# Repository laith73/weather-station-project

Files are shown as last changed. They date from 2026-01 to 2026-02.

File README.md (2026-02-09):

# Project Description

This is a design for a weather station device that provides multiple essential metrics for real-world weather scenarios. This device can be used in various settings, including homes, farms, and offices, allowing users to gain insight into the weather without leaving the comfort of their own place. Additionally, the device provides a simple web dashboard accessible locally to display the sensors' readings on the user's computer or phone, as well as a small OLED display on the device for easy local monitoring.

This repo contains all of the KiCad project files, reports, and datasheets for the parts used.

# Contributors

- Laith Al Sairafi, laith73@iastate.edu
- Luke Post, lpost@iastate.edu

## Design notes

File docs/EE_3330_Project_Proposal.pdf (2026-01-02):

# EE 3330 Project Proposal - Weather Station

### Laith Al Sairafi and Luke Post

### September 10th 2025

## Project Description and Details

For our project, we plan to design a weather station device that provides multiple essential metrics used in real-world weather scenarios. This device could be used in homes, allowing users to gain insight into the weather without leaving the comfort of their own homes. Additionally, we plan to create a simple web dashboard that can be accessed locally to display the sensors’ readings on the user’s computer or phone. Since the ESP32 microcontroller features a built-in WiFi module, as well as a small display, it will facilitate easy local monitoring.

The sensors we are planning to use for this project are the following:

- Temperature
- Humidity
- Barometric pressure
- UV
- GPS

However, depending on the project’s progress throughout the semester, more sensors could be added later.

## Team Members

- Laith Al Sairafi, email: laith73@iastate.edu
- Luke Post, email: lpost@iastate.edu

1

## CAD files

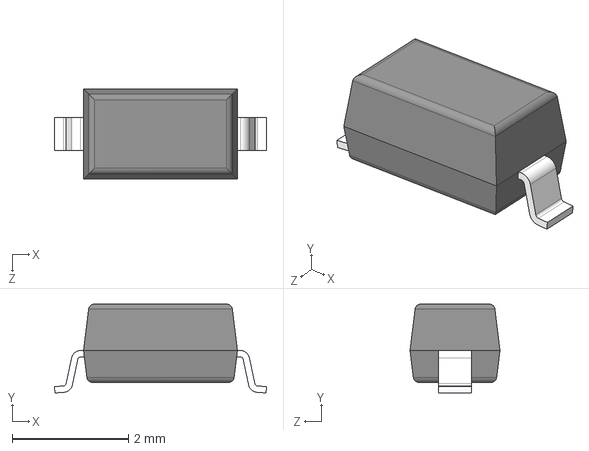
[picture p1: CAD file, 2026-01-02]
kicad files/Models/1N5819HW_7_F/1N5819HW-7-F.step
3.65 x 1.53 x 1.55 mm

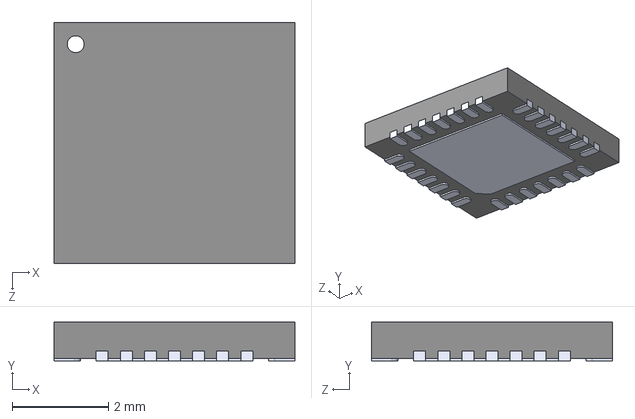
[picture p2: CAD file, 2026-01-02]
kicad files/Models/CP2102N_A02_GQFN28/CP2102N-A02-GQFN28.step
5.00 x 0.8 x 5.00 mm

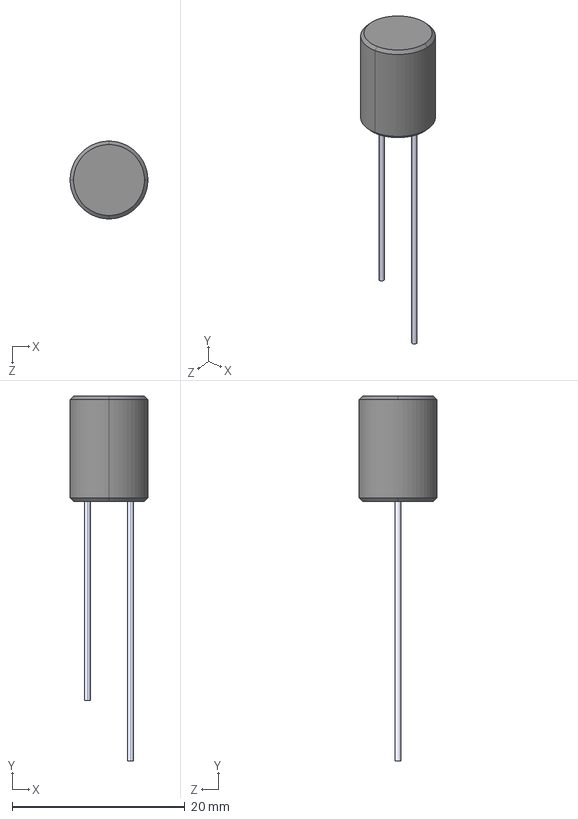
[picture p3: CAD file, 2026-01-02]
kicad files/Models/RLB9012_221KL/RLB9012-221KL.step
9.00 x 42.2 x 9.00 mm

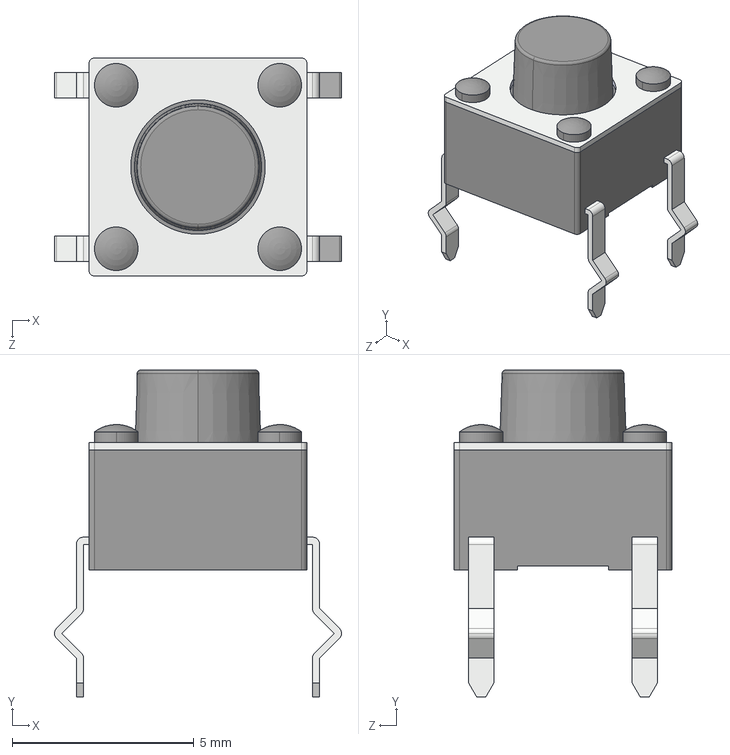
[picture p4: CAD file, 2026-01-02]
kicad files/Models/TS02_66_55_BK_100_LCR_D/TS02-66-55-BK-100-LCR-D.step
7.90 x 9.00 x 6.00 mm

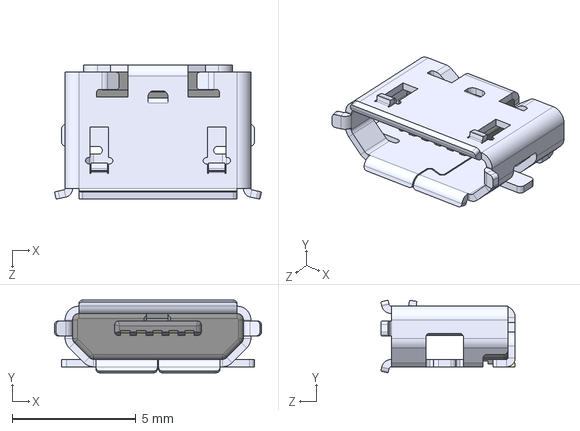
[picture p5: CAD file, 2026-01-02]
kicad files/Models/473460001/47346-0001.step
8.36 x 2.94 x 5.43 mm

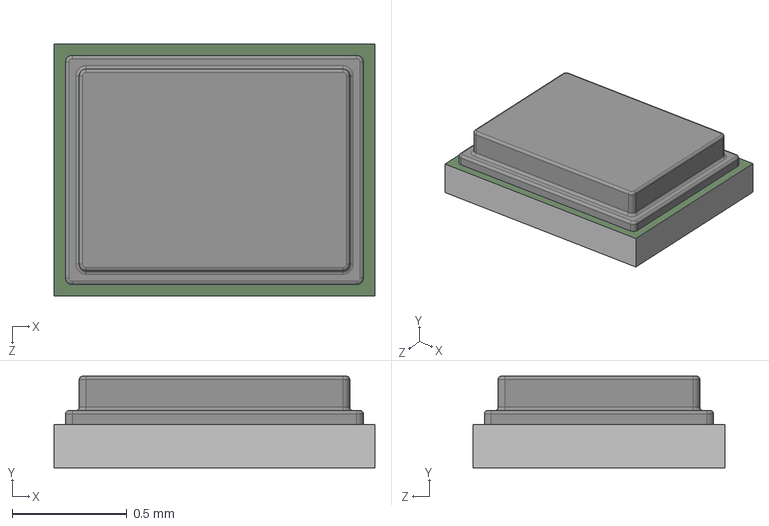
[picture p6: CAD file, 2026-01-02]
kicad files/Models/B4327/B39162B4327P810.step
1.40 x 0.4 x 1.10 mm

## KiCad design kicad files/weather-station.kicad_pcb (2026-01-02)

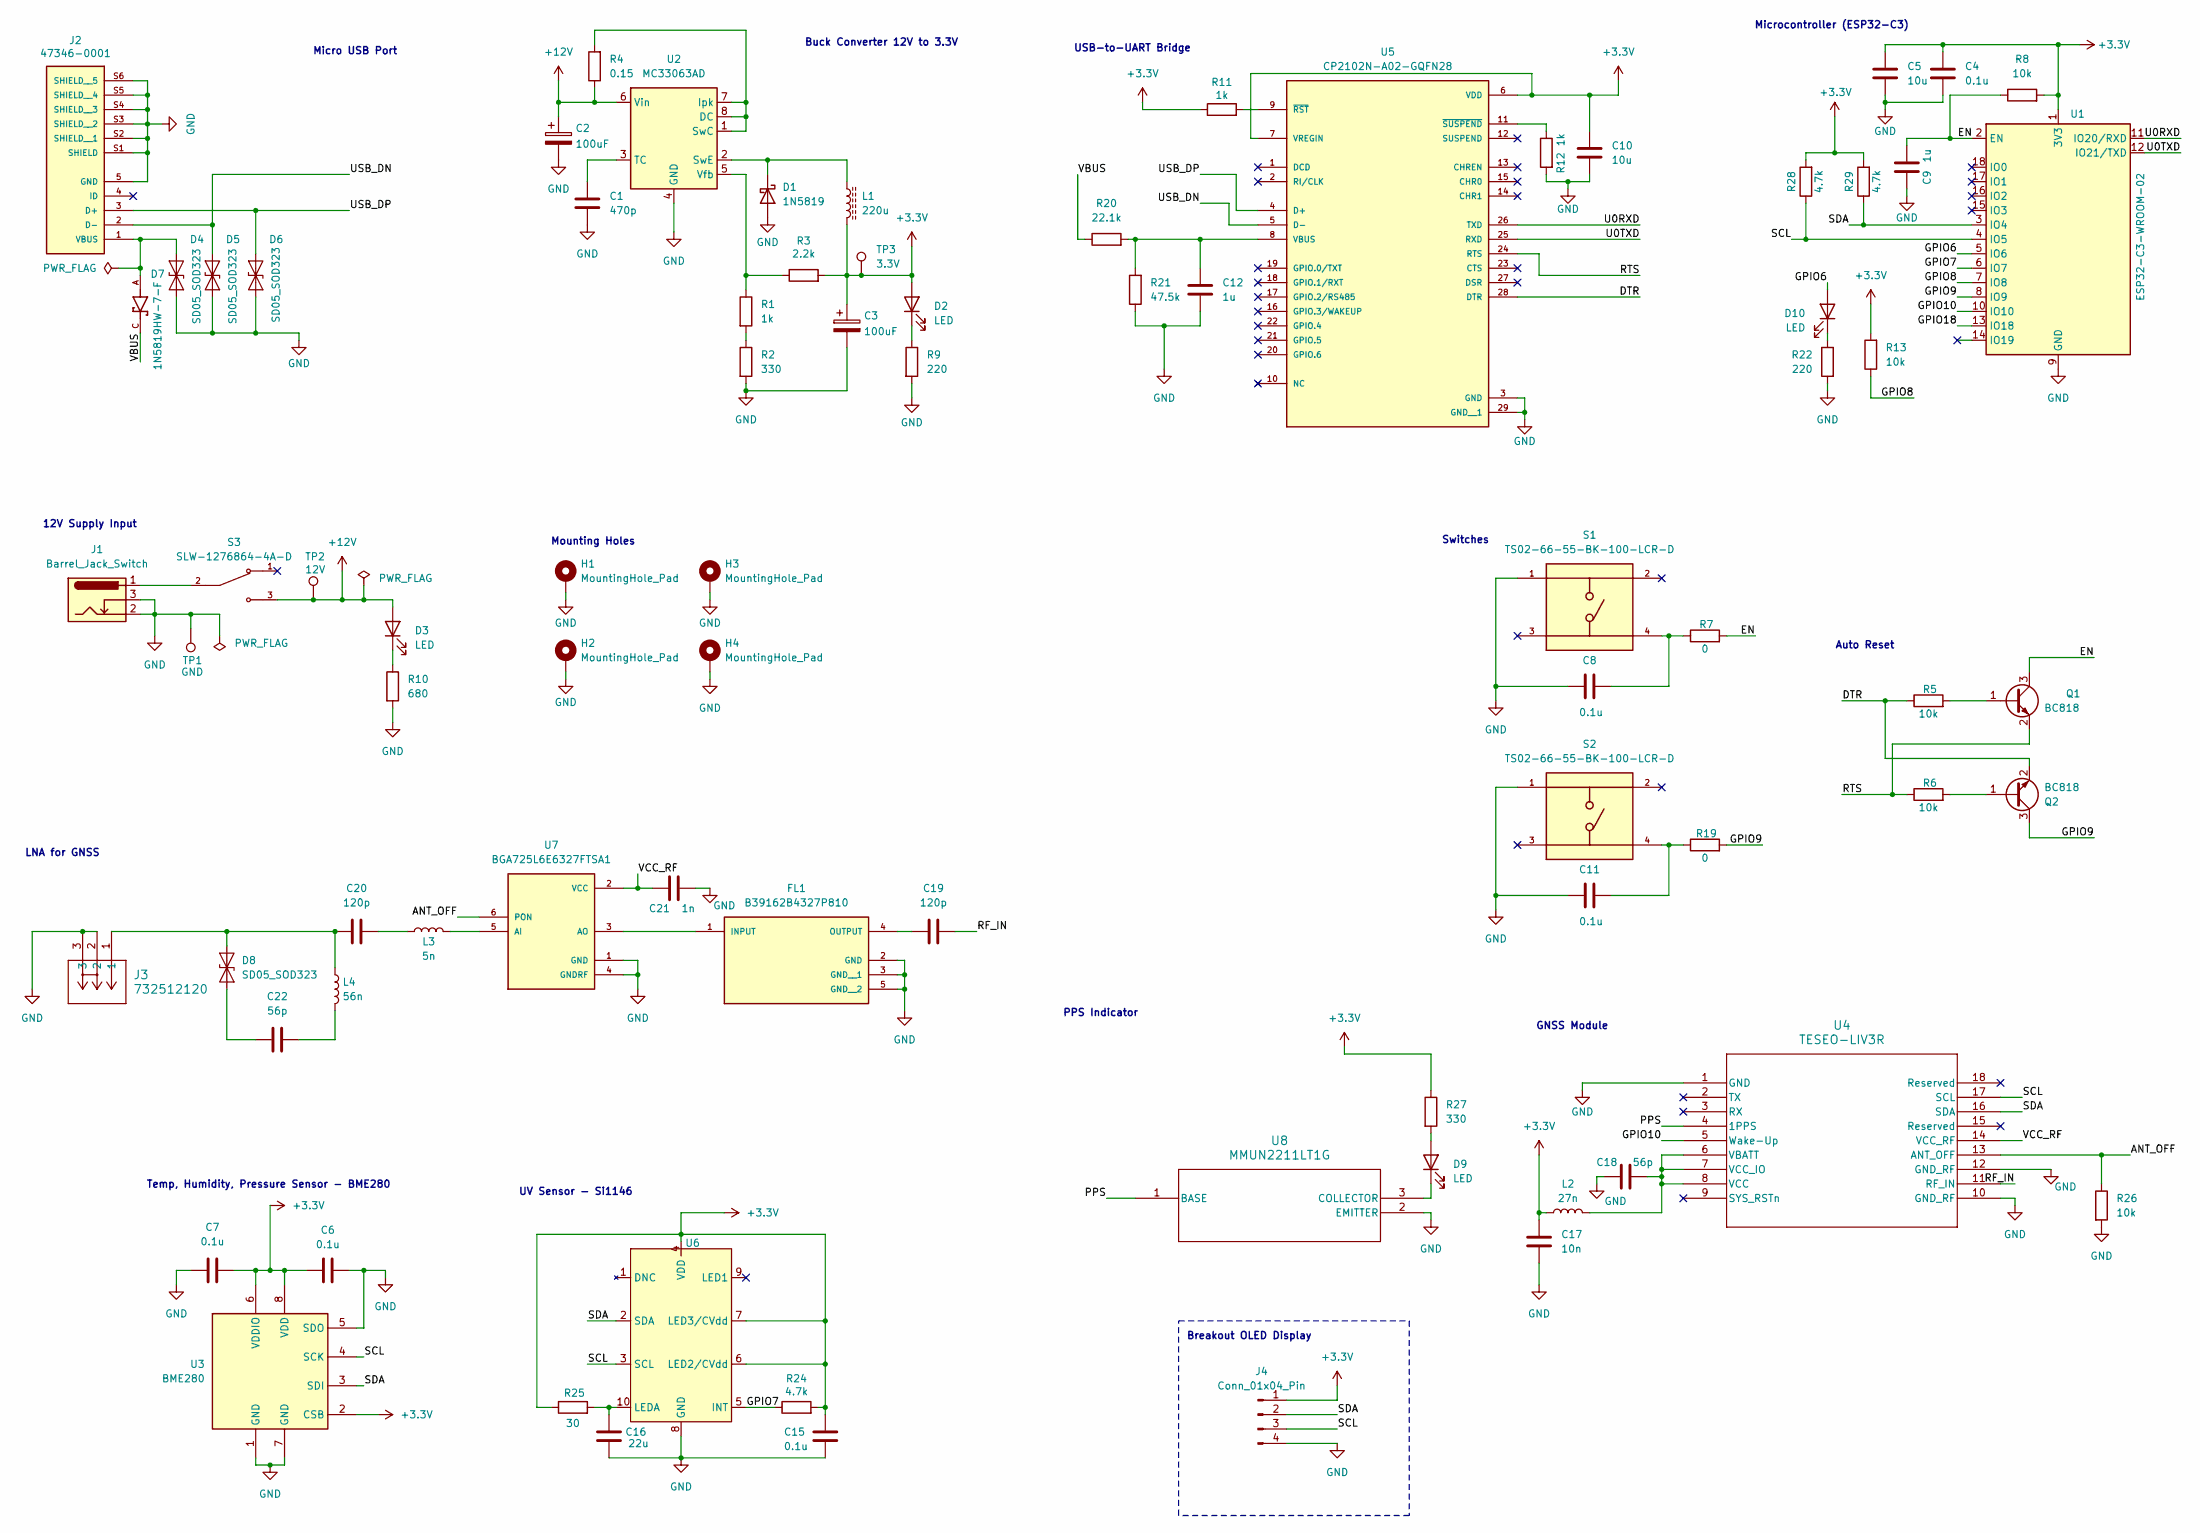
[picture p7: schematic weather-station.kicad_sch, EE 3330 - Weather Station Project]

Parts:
C1: 470p; C_0805_2012Metric_Pad1.18x1.45mm_HandSolder
C2, C3: 100uF; CP_Radial_D10.0mm_P5.00mm
C4, C6, C7, C8, C11, C15: 0.1u; C_0805_2012Metric_Pad1.18x1.45mm_HandSolder
C5, C10: 10u; C_0805_2012Metric_Pad1.18x1.45mm_HandSolder
C9, C12: 1u; C_0805_2012Metric_Pad1.18x1.45mm_HandSolder
C16: 22u; C_0805_2012Metric_Pad1.18x1.45mm_HandSolder
C17: 10n; C_0402_1005Metric_Pad0.74x0.62mm_HandSolder
C18, C22: 56p; C_0402_1005Metric_Pad0.74x0.62mm_HandSolder
C19, C20: 120p; C_0402_1005Metric_Pad0.74x0.62mm_HandSolder
C21: 1n; C_0402_1005Metric_Pad0.74x0.62mm_HandSolder
D1: 1N5819; D_DO-41_SOD81_P10.16mm_Horizontal
D2, D3, D9, D10: LED; LED_1206_3216Metric_Pad1.42x1.75mm_HandSolder
D4, D5, D6, D8: SD05_SOD323; D_SOD-323
D7: 1N5819HW-7-F; SOD3715X145N; PARTREV 18-2
FL1: B39162B4327P810; FIL_B39162B4327P810; PARTREV October 25, 2019
H1, H2, H3, H4: MountingHole_Pad; MountingHole_3.2mm_M3_ISO7380_Pad_TopBottom
J1: Barrel_Jack_Switch; BarrelJack_Horizontal
J2: 47346-0001; MOLEX_47346-0001; PARTREV E
J3: 732512120; CONN-732513152_MOL
J4: Conn_01x04_Pin; PinSocket_1x04_P2.54mm_Vertical
L1: 220u; IND_RLB9012-221KL
L2: 27n; L_0402_1005Metric_Pad0.77x0.64mm_HandSolder
L3: 5n; L_0402_1005Metric_Pad0.77x0.64mm_HandSolder
L4: 56n; L_0402_1005Metric_Pad0.77x0.64mm_HandSolder
Q1, Q2: BC818; SOT-23
R1, R11, R12: 1k; R_0805_2012Metric_Pad1.20x1.40mm_HandSolder
R2, R27: 330; R_0805_2012Metric_Pad1.20x1.40mm_HandSolder
R3: 2.2k; R_0805_2012Metric_Pad1.20x1.40mm_HandSolder
R4: 0.15; R_0805_2012Metric_Pad1.20x1.40mm_HandSolder
R5, R6, R8, R13: 10k; R_0805_2012Metric_Pad1.20x1.40mm_HandSolder
R7, R19: 0; R_0805_2012Metric_Pad1.20x1.40mm_HandSolder
R9, R22: 220; R_0805_2012Metric_Pad1.20x1.40mm_HandSolder
R10: 680; R_0805_2012Metric_Pad1.20x1.40mm_HandSolder
R20: 22.1k; R_0805_2012Metric_Pad1.20x1.40mm_HandSolder
R21: 47.5k; R_0805_2012Metric_Pad1.20x1.40mm_HandSolder
R24, R28, R29: 4.7k; R_0805_2012Metric_Pad1.20x1.40mm_HandSolder
R25: 30; R_0805_2012Metric_Pad1.20x1.40mm_HandSolder
R26: 10k; R_0402_1005Metric_Pad0.72x0.64mm_HandSolder
S1, S2: TS02-66-55-BK-100-LCR-D; SW_TS02-66-55-BK-100-LCR-D; PARTREV 1.0
S3: SLW-1276864-4A-D; SW_SLW-1276864-4A-D; PARTREV 1.01
TP1: GND; TestPoint_Keystone_5010-5014_Multipurpose
TP2: 12V; TestPoint_Keystone_5010-5014_Multipurpose
TP3: 3.3V; TestPoint_Keystone_5010-5014_Multipurpose
U1: ESP32-C3-WROOM-02
U2: MC33063AD; SOIC-8_3.9x4.9mm_P1.27mm
U3: BME280; Bosch_LGA-8_2.5x2.5mm_P0.65mm_ClockwisePinNumbering
U4: TESEO-LIV3R; ARRAY_LIV3R_STM
U5: CP2102N-A02-GQFN28; QFN50P500X500X80-29N; PARTREV 1.5
U6: Si1146; QFN-10_2.85x4.9_Pitch1mm
U7: BGA725L6E6327FTSA1; AMP_BGA725L6E6327FTSA1; PARTREV 2.0
U8: MMUN2211LT1G; SOT-23-3_1P4X3P040_ONS

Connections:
+3.3V: C3.1, C4.1, C5.1, C6.2, C7.1, C10.1, C15.1, C17.1, D2.2 (A), J4.1, L1.2, L2.1, R3.2, R8.2, R11.1, R13.2, R24.2, R25.1, R27.1, R28.2, R29.2, TP3.1, U1.1 (3V3), U3.2 (CSB), U3.6 (VDDIO), U3.8 (VDD), U5.6 (VDD), U5.7 (VREGIN), U6.4 (VDD), U6.6 (LED2/CVdd), U6.7 (LED3/CVdd)
+12V: C2.1, D3.2 (A), R4.1, S3.3, TP2.1, U2.6 (Vin)
/ANT_OFF: R26.1, U4.13 (ANT_OFF), U7.6 (PON)
/DTR: Q2.2 (E), R5.1, U5.28 (DTR)
/EN: C9.2, Q1.3 (C), R7.2, R8.1, U1.2 (EN)
/GPIO6: D10.2 (A), U1.5 (IO6)
/GPIO7: R24.1, U1.6 (IO7), U6.5 (INT)
/GPIO8: R13.1, U1.7 (IO8)
/GPIO9: Q2.3 (C), R19.2, U1.8 (IO9)
/GPIO10: U1.10 (IO10), U4.5 (Wake-Up)
/GPIO18: U1.13 (IO18)
/PPS: U4.4 (1PPS), U8.1 (BASE)
/RF_IN: C19.2, U4.11 (RF_IN)
/RTS: Q1.2 (E), R6.1, U5.24 (RTS)
/SCL: J4.3, R28.1, U1.4 (IO5), U3.4 (SCK), U4.17 (SCL), U6.3 (SCL)
/SDA: J4.2, R29.1, U1.3 (IO4), U3.3 (SDI), U4.16 (SDA), U6.2 (SDA)
/U0RXD: U1.11 (IO20/RXD), U5.26 (TXD)
/U0TXD: U1.12 (IO21/TXD), U5.25 (RXD)
/USB_DN: D5.2 (A2), J2.2 (D-), U5.5 (D-)
/USB_DP: D6.2 (A2), J2.3 (D+), U5.4 (D+)
/VBUS: D7.C, R20.1
/VCC_RF: C21.1, U4.14 (VCC_RF), U7.2 (VCC)
GND: C1.2, C2.2, C3.2, C4.2, C5.2, C6.1, C7.2, C8.1, C9.1, C10.2, C11.1, C12.2, C15.2, C16.2, C17.2, C18.1, C21.2, D1.2 (A), D4.1 (A1), D5.1 (A1), D6.1 (A1), FL1.2 (GND), FL1.3 (GND__1), FL1.5 (GND__2), H1.1, H2.1, H3.1, H4.1, J1.2, J1.3, J2.5 (GND), J2.S1 (SHIELD), J2.S2 (SHIELD__1), J2.S3 (SHIELD__2), J2.S4 (SHIELD__3), J2.S5 (SHIELD__4), J2.S6 (SHIELD__5), J3.2, J3.3, J4.4, R2.2, R9.2, R10.2, R12.2, R21.1, R22.2, R26.2, S1.1, S2.1, TP1.1, U1.9 (GND), U1.19 (GND), U2.4 (GND), U3.1 (GND), U3.5 (SDO), U3.7 (GND), U4.1 (GND), U4.10 (GND_RF), U4.12 (GND_RF), U5.3 (GND), U5.29 (GND__1), U6.8 (GND), U7.1 (GND), U7.4 (GNDRF), U8.2 (EMITTER)
unnamed: C8.2, R7.1, S1.4
unnamed: C11.2, R19.1, S2.4
unnamed: C20.2, L3.1
unnamed: C22.2, L4.2
unnamed: D1.1 (K), L1.1, U2.2 (SwE)
unnamed: D2.1 (K), R9.1
unnamed: D3.1 (K), R10.1
unnamed: D4.2 (A2), D7.A, J2.1 (VBUS)
unnamed: C22.1, D8.1 (A1)
unnamed: C20.1, D8.2 (A2), J3.1, L4.1
unnamed: D9.2 (A), R27.2
unnamed: D9.1 (K), U8.3 (COLLECTOR)
unnamed: D10.1 (K), R22.1
unnamed: FL1.1 (INPUT), U7.3 (AO)
unnamed: C19.1, FL1.4 (OUTPUT)
unnamed: J1.1, S3.2
unnamed: Q1.1 (B), R5.2
unnamed: Q2.1 (B), R6.2
unnamed: R1.2, R2.1
unnamed: R4.2, U2.1 (SwC), U2.7 (Ipk), U2.8 (DC)
unnamed: C1.1, U2.3 (TC)
unnamed: R1.1, R3.1, U2.5 (Vfb)
unnamed: C18.2, L2.2, U4.6 (VBATT), U4.7 (VCC_IO), U4.8 (VCC)
unnamed: C12.1, R20.2, R21.2, U5.8 (VBUS)
unnamed: R11.2, U5.9 (~RST)
unnamed: R12.1, U5.11 (~SUSPEND)
unnamed: C16.1, R25.2, U6.10 (LEDA)
unnamed: L3.2, U7.5 (AI)

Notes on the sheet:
Auto Reset
12V Supply Input
Switches
USB-to-UART Bridge
UV Sensor - Si1146
LNA for GNSS
GNSS Module
Temp, Humidity, Pressure Sensor - BME280
PPS Indicator
Breakout OLED Display
Microcontroller (ESP32-C3)
Buck Converter 12V to 3.3V
Micro USB Port
Mounting Holes

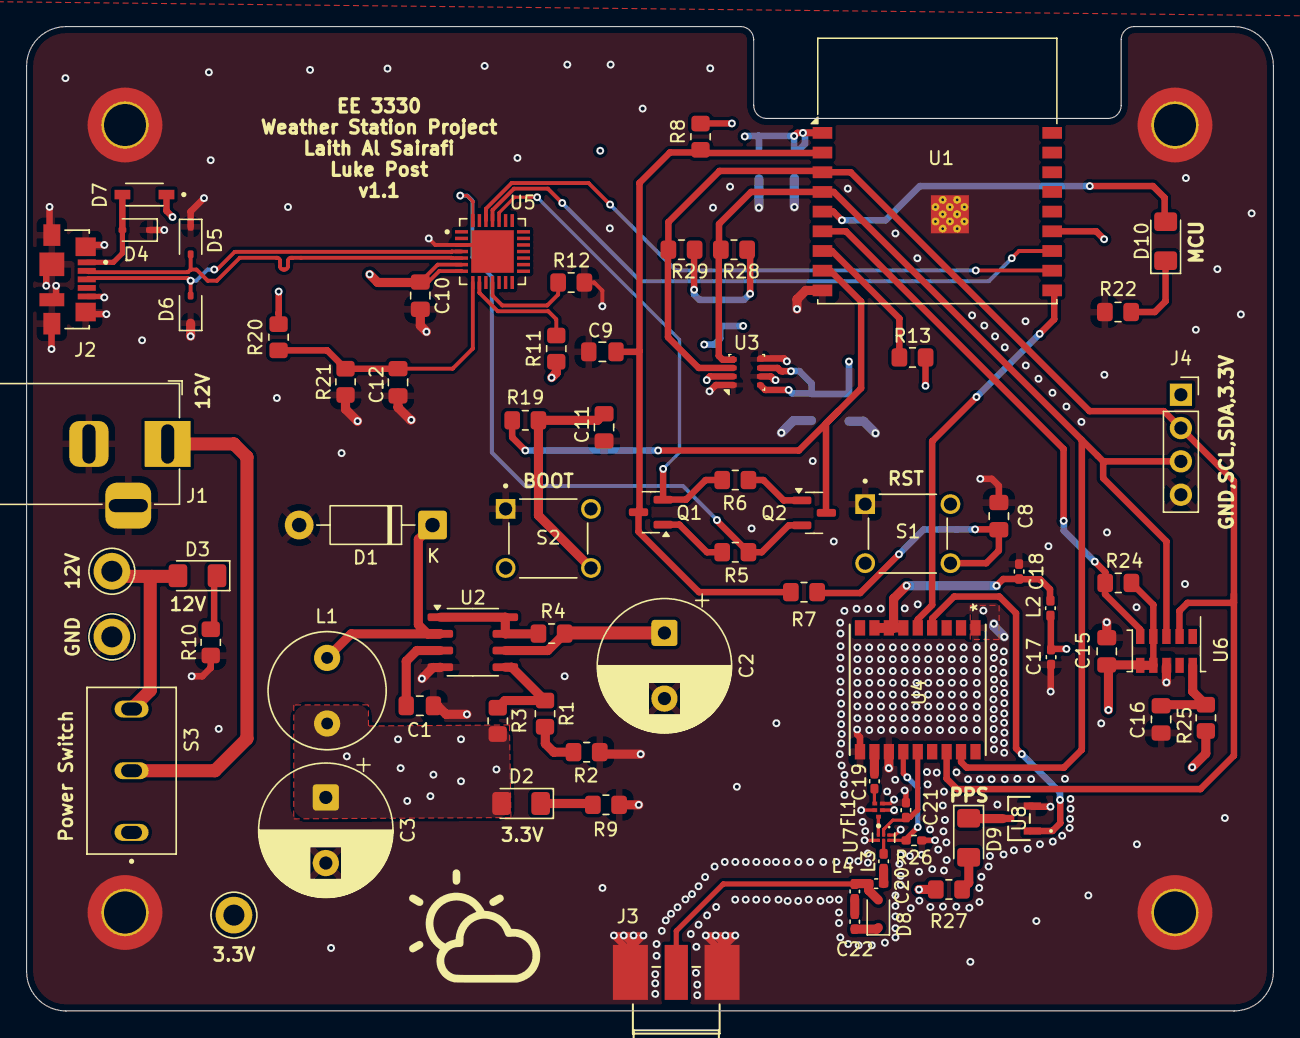
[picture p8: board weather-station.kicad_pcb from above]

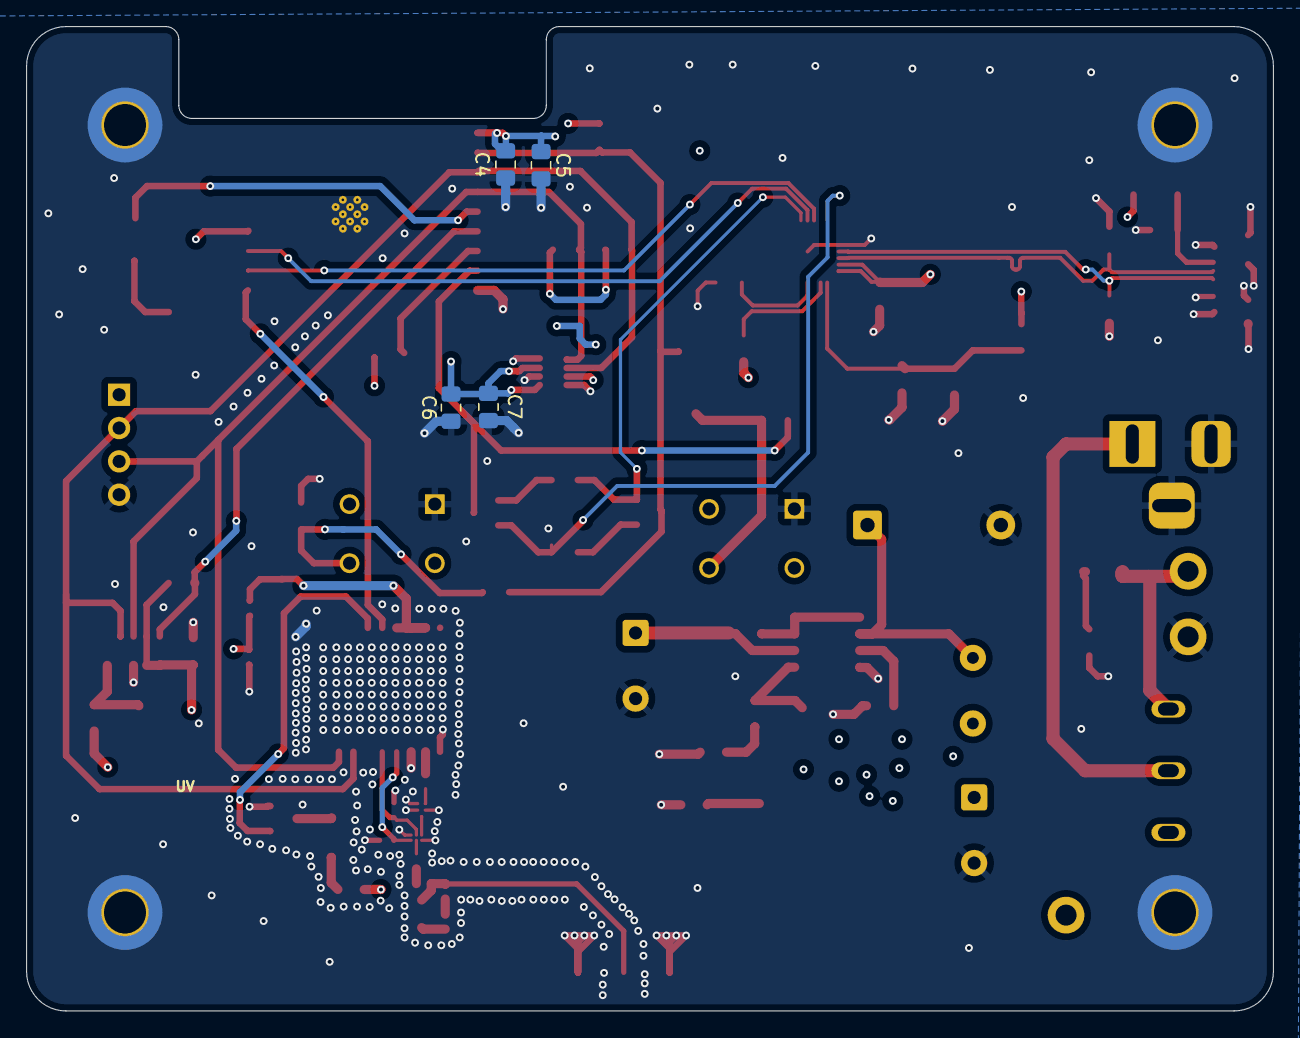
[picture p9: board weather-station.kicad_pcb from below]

Board: 4 copper layers, 95.0 x 75.0 mm, 82 parts (4 on the bottom side), 50 nets.

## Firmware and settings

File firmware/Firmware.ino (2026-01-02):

/*
  Weather Station Project Firmware
  Author: Laith Al Sairafi
  Date: Fall 2025
*/

#include <Wire.h>
#include "SparkFunBME280.h"
#include <SI1145_WE.h>
#include <TinyGPSPlus.h>
#include <WiFi.h>
#include <ESPAsyncWebServer.h>
#include <LittleFS.h>
#include <ArduinoJson.h>

// Constants
#define SDA_PIN 4
#define SCL_PIN 5       
#define BME280_ADDR 0x76    // I2C address of BME280
#define SI1145_ADDR 0x60    // I2C address of Si1145
#define TESEO_ADDR 0x3A     // I2C address of Teseo-LIV3R
#define READ_SIZE 32        // number of bytes to request per cycle
#define READ_INTERVAL 5000  // milliseconds

// Sensor objects
BME280 bme280;
SI1145_WE si1145 = SI1145_WE();
TinyGPSPlus gps;

// Wi-Fi credentials - user needs to update this
const char* ssid  = "Coolest Project";
const char* password = "123456789";

// Web server
AsyncWebServer server(80);

// Sensor variables
float lat = 0.0;
float lng = 0.0;
float alt = 0.0;
int satNum = 0;
float hdop = 0.0;
float hum = 0.0;
float temp = 0.0;
float pres = 0.0;
byte failureCode = 0;
unsigned int amb_als = 0;
unsigned int amb_ir = 0;
unsigned int proximity = 0;
float uv = 0.0;

// Time variables 
unsigned long lastReadTime  = 0;

/*
  Funcation to update the GPS data (lat, lng, alt, satNum, hdop)
  using the Teseo-LIV3R module
  @returns true if data is updated, false otherwise. 
*/ 
bool updateGPS(unsigned long timeoutMs = 500) {
  unsigned long start = millis();
  bool updated = false;

  while (millis() - start < timeoutMs) {
    int returned = Wire.requestFrom((int)TESEO_ADDR, READ_SIZE);

    while (Wire.available()) {
      char c = Wire.read();
      gps.encode(c);

      if (gps.location.isUpdated()) {
        lat = gps.location.lat();
        lng = gps.location.lng();
        alt = gps.altitude.meters();
        satNum = gps.satellites.value();
        hdop = gps.hdop.hdop();
        updated = true;
      }
    }

    delay(20);
  }

  return updated;
}

/*
  Funcation to update the environmental data data (hum, pres, temp)
  using the BME280 module
*/ 
void updateBME280(){
  hum = bme280.readFloatHumidity(); // percent
  pres = bme280.readFloatPressure() / 100; // hPa
  temp = bme280.readTempC(); // C
}

/*
  Funcation to update the environmental data data (amb_als, amb_ir, proximity, uv)
  using the Si1145 module
*/ 
void updateSi1145(){
  
  amb_als = si1145.getAlsVisData();
  amb_ir = si1145.getAlsIrData();
  proximity = si1145.getPsData();
  uv = si1145.getUvIndex();

  failureCode = si1145.getFailureMode();  // reads the response register
  if((failureCode&128)){  // if bit 7 is set in response register, there is a failure
    handleFailure(failureCode);
  }
}

void handleFailure(byte code){
  String msg = "";
  switch(code){
    case SI1145_RESP_INVALID_SETTING:
      msg = "Invalid Setting";
      break;
    case SI1145_RESP_PS1_ADC_OVERFLOW:
      msg = "PS ADC Overflow";
      break;
    case SI1145_RESP_ALS_VIS_ADC_OVERFLOW:
      msg = "ALS VIS ADC Overflow";
      break;
    case SI1145_RESP_ALS_IR_ADC_OVERFLOW:
      msg = "ALS IR Overflow";
      break;
    case SI1145_RESP_AUX_ADC_OVERFLOW:
      msg = "AUX ADC Overflow";
      break;
    default:
      msg = "Unknown Failure";
      break;
  }
  
  Serial.println(msg); 
  si1145.clearFailure();
}

void setup() {
  
  // Serial Setup
  Serial.begin(115200);
  delay(1000);
  
  // I2C setup
  Wire.setPins(SDA_PIN, SCL_PIN);
  Wire.begin();
  Wire.setClock(100000);

  // BME280 sensor setup
  bme280.setI2CAddress(BME280_ADDR);
  while(!bme280.beginI2C()){
    Serial.println("The BME280 sensor did not respond.");
    delay(1000);
  }

  // Si1145 sensor setup
  si1145.init();
  
  // si1145.enableHighSignalVisRange(); // Gain divided by 14.5
  // si1145.enableHighSignalIrRange(); // Gain divided by 14.5
  // si1145.enableHighSignalPsRange(); // Gain divided by 14.5

  si1145.disableHighSignalVisRange(); // Gain NOT divided by 14.5
  si1145.disableHighSignalIrRange(); // Gain NOT divided by 14.5
  si1145.disableHighSignalPsRange(); // Gain NOT divided by 14.5

  si1145.enableMeasurements(PSALSUV_TYPE, AUTO);

  // Initialize LittleFS
  if (!LittleFS.begin()) {
      Serial.println("LittleFS Mount Failed!");
  }
  
  // Connect to Wi-Fi
  // WiFi.begin(ssid, password);  // Connect to Wi-Fi
  
  // Serial.print("Connecting");
  // while (WiFi.status() != WL_CONNECTED) {
  //   delay(500);
  //   Serial.print(".");
  // }

  // Serial.println();
  // Serial.println("Connected to Wi-Fi!");
  // Serial.print("IP Address: ");
  // Serial.println(WiFi.localIP());


  WiFi.softAP(ssid, password);

  IPAddress IP = WiFi.softAPIP();
  Serial.print("AP IP address: ");
  Serial.println(IP);
  
  // --- Web Server Endpoints ---

  // Handler for serving the html file 
  server.on("/", HTTP_GET, [](AsyncWebServerRequest *request) {
    if (LittleFS.exists("/index.html")) {
      request->send(LittleFS, "/index.html", "text/html");
    } else {
      request->send(500, "text/plain", "index.html not found");
    }
  });

  // Handler for real-time JSON data
  server.on("/data", [](AsyncWebServerRequest *request) {
    StaticJsonDocument<256> doc;

    doc["temperature"] = temp;
    doc["humidity"] = hum;
    doc["pressure"] = pres;
    doc["UV-Index"] = uv;
    doc["Ambient Light"] = amb_als;
    doc["Infrared Light"] = amb_ir;
    doc["proximity"] = proximity;
    doc["latitude"] = lat;
    doc["longitude"] = lng;
    doc["altitude"] = alt;
    doc["satellites"] = satNum;
    doc["HDOP"] = hdop;

    // Serialize to string
    String output;
    serializeJson(doc, output);
    request->send(200, "application/json", output);
  });

  server.begin();
  Serial.println("HTTP server started.");
}

void loop() {
  
  unsigned long currentTime = millis();
  
  if (currentTime - lastReadTime >= READ_INTERVAL) {
    
    bool gpsOK = updateGPS();
        
    if (!gpsOK) {
      Serial.println("GPS timeout — no new fix");
    } else {
      Serial.println("GPS updated");
    }

    updateBME280();
    Serial.println("BME280 updated");
    updateSi1145();
    Serial.println("Si1145 updated");

    Serial.print("Temperature: ");
    Serial.println(temp);  
    Serial.print("Humidity: ");
    Serial.println(hum);  
    Serial.print("Pressure: ");
    Serial.println(pres);
    Serial.print("Ambient Light: ");
    Serial.println(amb_als);
    Serial.print("Infrared Light: ");
    Serial.println(amb_ir);
    Serial.print("UV-Index: ");
    Serial.println(uv);
    Serial.print("Proximity: ");
    Serial.println(proximity);
    Serial.print("Lat: "); 
    Serial.println(lat, 6);
    Serial.print("Lon: "); 
    Serial.println(lng, 6);
    Serial.print("Alt: "); 
    Serial.println(alt, 2);
    Serial.print("Satellites: ");
    Serial.println(satNum);
    Serial.print("HDOP: "); 
    Serial.println(hdop);
    Serial.println("------------------------------------");
    
    lastReadTime = currentTime;
  }
}
